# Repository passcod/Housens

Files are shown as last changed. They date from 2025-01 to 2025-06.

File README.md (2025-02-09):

# Housens

Project to make my own low-power house sensors.

Current iteration (r002):

- Bluetooth
- ambient light (OPT3005)
- pressure, humidity, temperature (BME280)
- carbon dioxide (STCC4)
- STM32WB core
- powered from CR2032
- 50x50mm

Hardware licensed [CERN-OHL-S](https://ohwr.org/project/cernohl/-/wikis/uploads/b236492596cfc91c12def7d50bbf7da0/cern_ohl_s_v2.pdf).

Firmware licensed [GPL-3.0-or-later](https://opensource.org/license/gpl-3-0).

## Renders

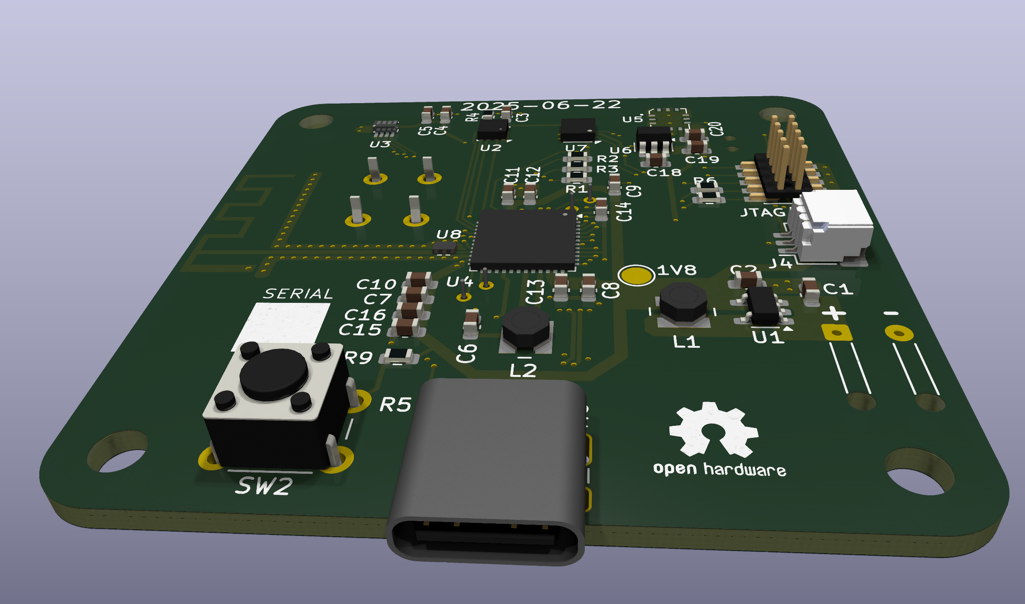
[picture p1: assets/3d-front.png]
front 3D render


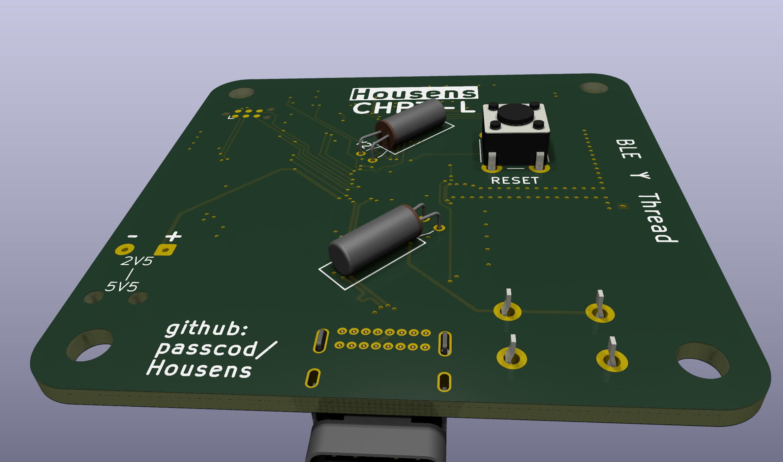
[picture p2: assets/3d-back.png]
back 3D render


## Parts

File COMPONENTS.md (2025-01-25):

# Components

- BME280 sensor
  - Temperature, Humidity, Pressure
  - 3.6 uA @ 1Hz typical
  - 1.8V power
- OPT3005 sensor
  - Ambient light, with IR filter
  - 1.8 uA typical
  - 1.8V power
- STM32WB
  - STM32WB55CG   (LCD,   1MB flash / 256kB ram), or:
    - STM32WB55CE (LCD, 512kB flash / 256kB ram)
    - STM32WB55CC (LCD, 256kB flash / 128kB ram)
    - STM32WB35CE (---, 512kB flash /  96kB ram)
    - STM32WB35CC (---, 256kB flash /  96kB ram)
  - ARM Cortex-M4
  - BLE5 and Thread
  - 1.8V power
  - 90 uA per MHz, up to 64MHz
  - Rust support
- CR2032
  - 2.7V flat
  - 3V nominal
  - 3.4V max
  - 210 mAh typical
- MCP1603
  - Voltage switching regulator
  - 2.7 - 4.5V input
  - 1.8V output
  - 45 uA quiescent, 0.1 uA shutdown
  - 500 mA max output

## Power usage

- load: 3.6 uA + 1.8 uA + 90 uA * 64 + 45 uA = ~6mA
- so ~36 hour battery life @ 1Hz update constant power

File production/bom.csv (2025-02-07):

Designator | Footprint | Quantity | Value | LCSC Part #
AE1 | Texas_SWRA117D_2.4GHz_Right_BigHole | 1 | 2.4GHz
BT1 | BAT-HLD-001_2Pins | 1 | CR2032
C1, C10, C13, C2, C6 | 0603 | 5 | 4.7u
C11 | 0603 | 1 | 10n
C12 | 0603 | 1 | 1u
C14, C15, C3, C4, C5, C7, C8, C9 | 0603 | 8 | 100n
C16 | 0603 | 1 | 100p
C18, C19, C20 | 0603 | 3 | 220n
J1 | PinHeader_2x05_P1.27mm_Vertical_SMD | 1 | JTAG/SWD
J2 | USB_C_Receptacle_GCT_USB4085 | 1 | USB_C_2.0
J4 | JST_SH_SM03B-SRSS-TB_1x03-1MP_P1.00mm_Horizontal | 1 | RPI_SWD
L1 | L_Wuerth_WE-TPC-2811 | 1 | 4.7u
L2 | L_Wuerth_WE-TPC-2811 | 1 | 2.2u
R1, R2, R3, R5, R9 | 0603 | 5 | 10k
R4 | 0603 | 1 | 100k
R6, R7 | 0603 | 2 | 100
SW1 | SW_PUSH_6mm | 1 | RESET
SW2 | SW_PUSH_6mm | 1 | USER
TP1 | TestPoint_Pad_D2.0mm | 1 | TestPoint
U1 | TSOT-23-5 | 1 | LM3670MF
U2 | Bosch_LGA-8_2.5x2.5mm_P0.65mm_ClockwisePinNumbering | 1 | BME280
U3 | OPT3005DTSR | 1 | OPT3005
U4 | QFN-48-1EP_7x7mm_P0.5mm_EP5.6x5.6mm_ThermalVias_OneSided | 1 | STM32WB55CGUx
U5 | STCC4-PROVISIONAL | 1 | STCC4
U6 | SOT-23-6 | 1 | REG710NA-3.3
U7 | DFN-14-1EP_3x2mm_P0.4mm_EP1.78x1.35mm_AP22966 | 1 | AP22966
U8 | MLPF-WB55-01E3 | 1 | MLPF-WB55-01E3
Y1 | Crystal_SMD_2016-4Pin_2.0x1.6mm | 1 | 32MHz
Y2 | Crystal_AT310_D3.0mm_L10.0mm_Horizontal | 1 | 32.768kHz

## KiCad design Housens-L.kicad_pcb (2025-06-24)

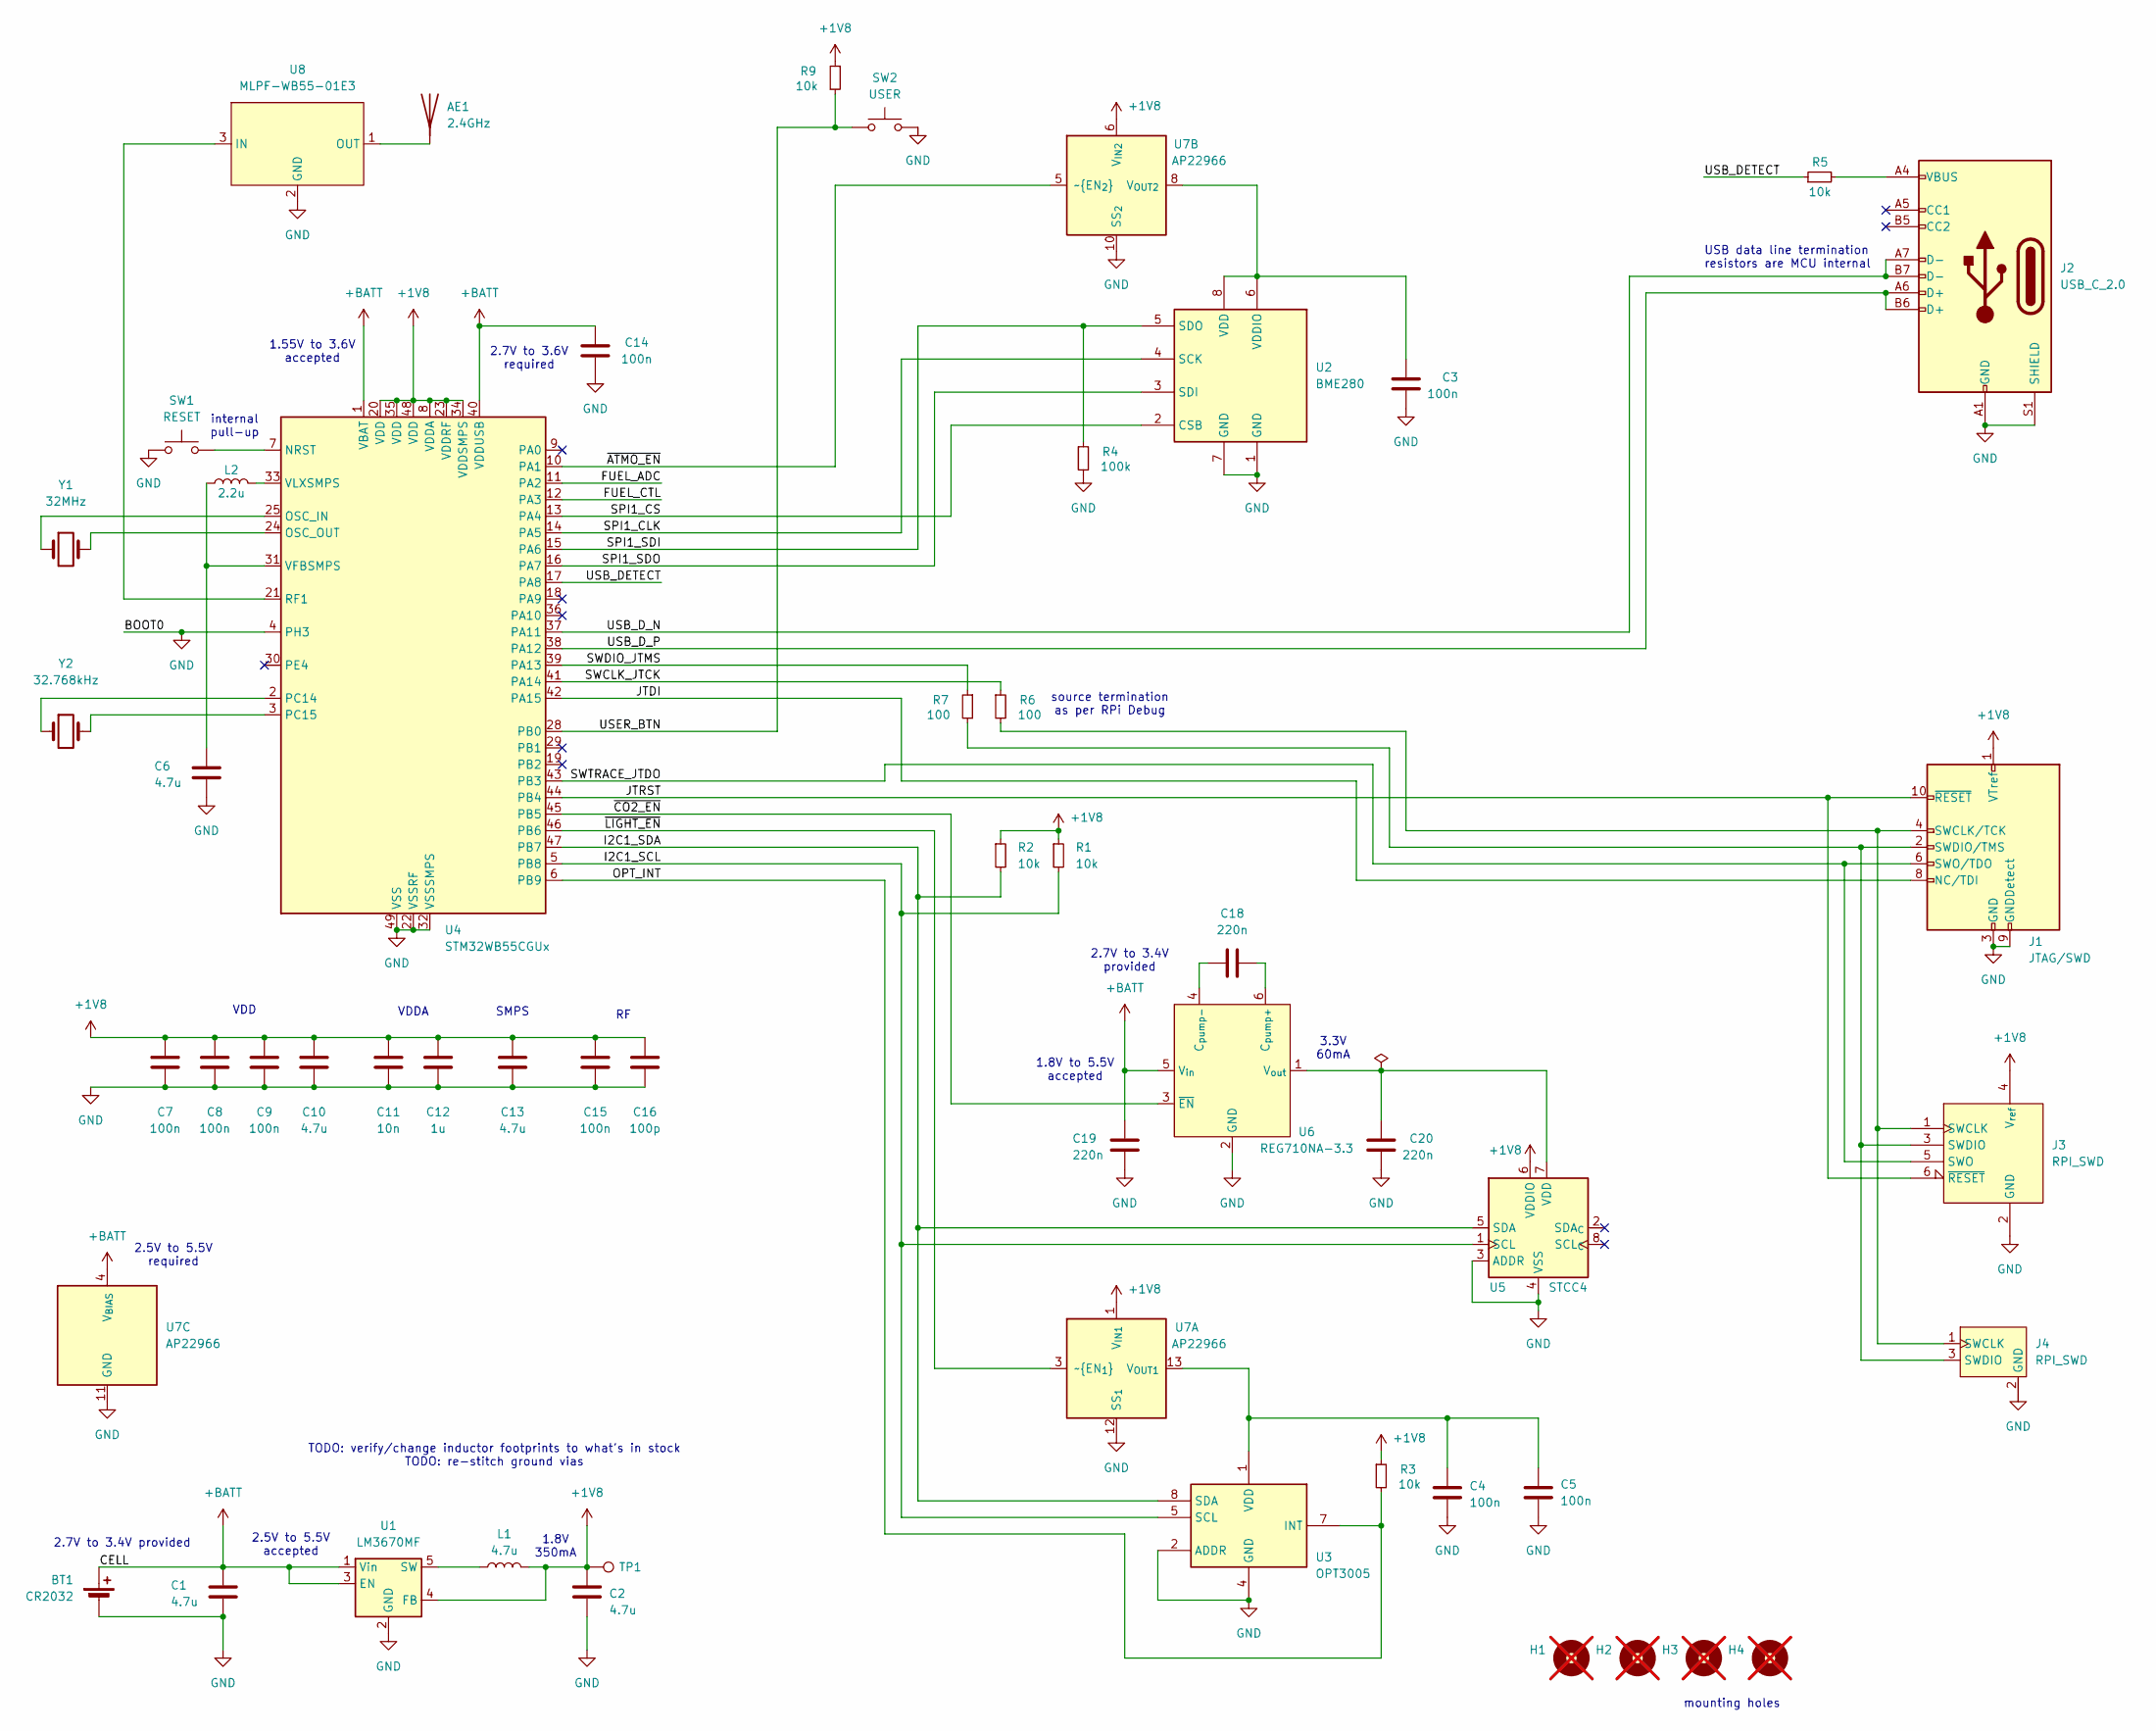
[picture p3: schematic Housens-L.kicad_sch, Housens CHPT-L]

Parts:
AE1: 2.4GHz; Texas_SWRA117D_2.4GHz_Right_BigHole
BT1: CR2032; SolderWire-0.1sqmm_1x02_P3.6mm_D0.4mm_OD1mm_Relief
C1, C2, C6, C10, C13: 4.7u; C_0603_1608Metric
C3, C4, C5, C7, C8, C9, C14, C15: 100n; C_0603_1608Metric
C11: 10n; C_0603_1608Metric
C12: 1u; C_0603_1608Metric
C16: 100p; C_0603_1608Metric
C18, C19, C20: 220n; C_0603_1608Metric
H1, H2, H3, H4: MountingHole_M3; MountingHole_3.2mm_M3; not fitted
J1: JTAG/SWD; PinHeader_2x05_P1.27mm_Vertical_SMD
J2: USB_C_2.0; USB_C_Receptacle_GCT_USB4085
J3: RPI_SWD; Tag-Connect_TC2030-IDC-NL_2x03_P1.27mm_Vertical
J4: RPI_SWD; JST_SH_SM03B-SRSS-TB_1x03-1MP_P1.00mm_Horizontal
L1: 4.7u; L_Wuerth_WE-TPC-2811
L2: 2.2u; L_Wuerth_WE-TPC-2811
R1, R2, R3, R5, R9: 10k; R_0603_1608Metric
R4: 100k; R_0603_1608Metric
R6, R7: 100; R_0603_1608Metric
SW1: RESET; SW_PUSH_6mm
SW2: USER; SW_PUSH_6mm
TP1: TestPoint; TestPoint_Pad_D2.0mm
U1: LM3670MF; TSOT-23-5; Part LM3670MFX-1.8/NOPB
U2: BME280; Bosch_LGA-8_2.5x2.5mm_P0.65mm_ClockwisePinNumbering
U3: OPT3005; OPT3005DTSR; Manufacturer_Part_Number OPT3005DTSR; Mouser Part Number 595-OPT3005DTSR
U4: STM32WB55CGUx; QFN-48-1EP_7x7mm_P0.5mm_EP3.5x3.5mm
U5: STCC4
U6: REG710NA-3.3; SOT-23-6
U7: AP22966; DFN-14-1EP_3x2mm_P0.4mm_EP1.78x1.35mm_AP22966
U8: MLPF-WB55-01E3
Y1: 32MHz; Crystal_C38-LF_D3.0mm_L8.0mm_Horizontal
Y2: 32.768kHz; Crystal_C38-LF_D3.0mm_L8.0mm_Horizontal

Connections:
+1V8: C2.1, C7.1, C8.1, C9.1, C10.1, C11.1, C12.1, C13.1, C15.1, C16.1, J1.1 (VTref), J3.4 (V_{ref}), L1.2, R1.1, R2.1, R3.1, R9.1, TP1.1, U1.4 (FB), U4.8 (VDDA), U4.20 (VDD), U4.23 (VDDRF), U4.34 (VDDSMPS), U4.35 (VDD), U4.48 (VDD), U5.6 (VDDIO), U7.1 (V_{IN1}), U7.2 (V_{IN1}), U7.6 (V_{IN2}), U7.7 (V_{IN2})
+BATT: BT1.1 (+), C1.1, C14.1, C19.1, U1.1 (Vin), U1.3 (EN), U4.1 (VBAT), U4.40 (VDDUSB), U6.5 (V_{in}), U7.4 (V_{BIAS})
/FUEL_ADC: U4.11 (PA2)
/FUEL_CTL: U4.12 (PA3)
/I2C1_SCL: R1.2, U3.5 (SCL), U4.5 (PB8), U5.1 (SCL)
/I2C1_SDA: R2.2, U3.8 (SDA), U4.47 (PB7), U5.5 (SDA)
/JTDI: J1.8 (NC/TDI), U4.42 (PA15)
/JTRST: J1.10 (~RESET), J3.6 (~RESET), U4.44 (PB4)
/OPT_INT: R3.2, U3.7 (INT), U4.6 (PB9)
/SPI1_CLK: U2.4 (SCK), U4.14 (PA5)
/SPI1_CS: U2.2 (CSB), U4.13 (PA4)
/SPI1_SDI: R4.1, U2.5 (SDO), U4.15 (PA6)
/SPI1_SDO: U2.3 (SDI), U4.16 (PA7)
/SWCLK_JTCK: R6.1, U4.41 (PA14)
/SWDIO_JTMS: R7.1, U4.39 (PA13)
/SWTRACE_JTDO: J1.6 (SWO/TDO), J3.5 (SWO), U4.43 (PB3)
/USB_DETECT: R5.1, U4.17 (PA8)
/USB_D_N: J2.A7 (D-), J2.B7 (D-), U4.37 (PA11)
/USB_D_P: J2.A6 (D+), J2.B6 (D+), U4.38 (PA12)
/USER_BTN: R9.2, SW2.2, U4.28 (PB0)
/~ATMO_EN: U4.10 (PA1), U7.5 (~EN_{2})
/~CO2_EN: U4.45 (PB5), U6.3 (~EN)
/~LIGHT_EN: U4.46 (PB6), U7.3 (~EN_{1})
GND: BT1.2 (-), C1.2, C2.2, C3.2, C4.2, C5.2, C6.2, C7.2, C8.2, C9.2, C10.2, C11.2, C12.2, C13.2, C14.2, C15.2, C16.2, C19.2, C20.2, J1.3 (GND), J1.5 (GND), J1.9 (GNDDetect), J2.A1 (GND), J2.A12 (GND), J2.B1 (GND), J2.B12 (GND), J2.S1 (SHIELD), J3.2 (GND), J4.2 (GND), R4.2, SW1.1, SW2.1, U1.2 (GND), U2.1 (GND), U2.7 (GND), U3.2 (ADDR), U3.4 (GND), U4.4 (PH3), U4.22 (VSSRF), U4.32 (VSSSMPS), U4.49 (VSS), U5.3 (ADDR), U5.4 (VSS), U6.2 (GND), U7.10 (SS_{2}), U7.11 (GND), U7.12 (SS_{1}), U7.15 (GND), U8.2 (GND), U8.4 (GND), U8.5 (GND), U8.6 (GND)
unnamed: AE1.1 (A), U8.1 (OUT)
unnamed: J1.4 (SWCLK/TCK), J3.1 (SWCLK), J4.1 (SWCLK), R6.2
unnamed: J1.2 (SWDIO/TMS), J3.3 (SWDIO), J4.3 (SWDIO), R7.2
unnamed: J2.A4 (VBUS), J2.A9 (VBUS), J2.B4 (VBUS), J2.B9 (VBUS), R5.2
unnamed: L1.1, U1.5 (SW)
unnamed: C3.1, U2.6 (VDDIO), U2.8 (VDD), U7.8 (V_{OUT2}), U7.9 (V_{OUT2})
unnamed: C4.1, C5.1, U3.1 (VDD), U7.13 (V_{OUT1}), U7.14 (V_{OUT1})
unnamed: SW1.2, U4.7 (NRST)
unnamed: U4.25 (OSC_IN), Y1.1
unnamed: U4.24 (OSC_OUT), Y1.2
unnamed: U4.2 (PC14), Y2.1
unnamed: U4.3 (PC15), Y2.2
unnamed: U4.21 (RF1), U8.3 (IN)
unnamed: C6.1, L2.1, U4.31 (VFBSMPS)
unnamed: L2.2, U4.33 (VLXSMPS)
unnamed: C20.1, U5.7 (VDD), U6.1 (V_{out})
unnamed: C18.2, U6.6 (C_{pump+})
unnamed: C18.1, U6.4 (C_{pump-})

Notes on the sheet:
SMPS
1.8V to 5.5V accepted
2.7V to 3.6V required
2.5V to 5.5V accepted
3.3V 60mA
2.7V to 3.4V provided
internal pull-up
2.7V to 3.4V provided
TODO: verify/change inductor footprints to what's in stock TODO: re-stitch ground vias
1.8V 350mA
source termination as per RPi Debug
mounting holes
USB data line termination resistors are MCU internal
2.5V to 5.5V required
VDDA
VDD
1.55V to 3.6V accepted

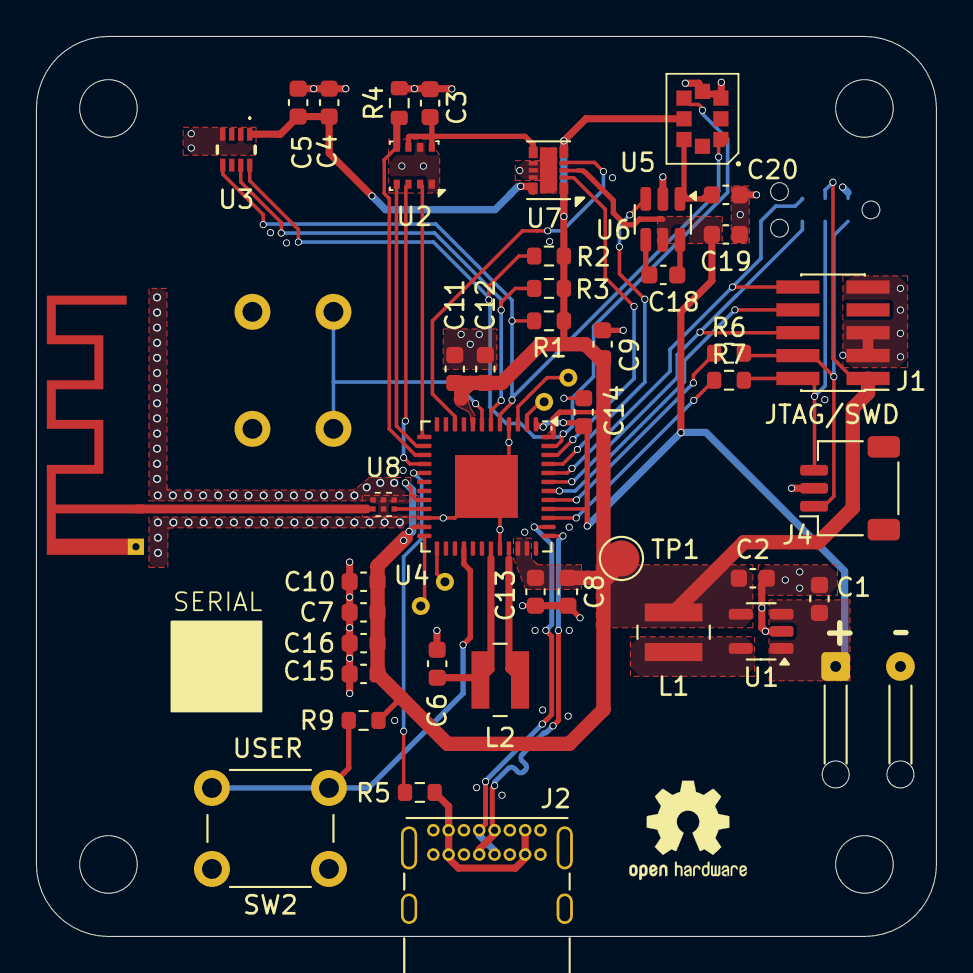
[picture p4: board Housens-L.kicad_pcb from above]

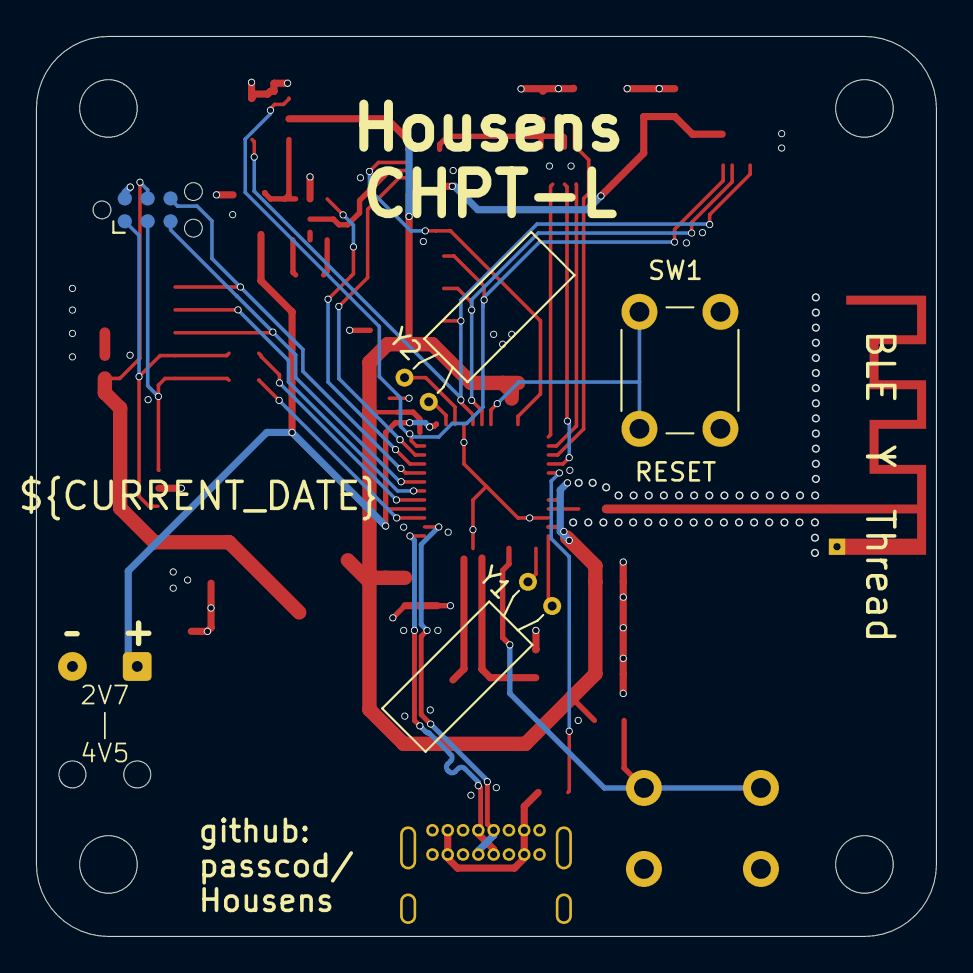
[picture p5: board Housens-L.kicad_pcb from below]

Board: 4 copper layers, 50.0 x 50.0 mm, 52 parts (4 on the bottom side), 40 nets.

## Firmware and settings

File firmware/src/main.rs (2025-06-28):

#![no_std]
#![no_main]

use defmt::*;
use embassy_executor::Spawner;
use embassy_stm32::gpio::{Level, Output, Speed, Input, Pull};
use embassy_time::Timer;
use {defmt_rtt as _, panic_probe as _};

#[embassy_executor::main]
async fn main(_spawner: Spawner) {
    let p = embassy_stm32::init(Default::default());
    info!("Hello World!");

    let mut led = Output::new(p.PB0, Level::High, Speed::Low);
    let mq = Input::new(p.PB2, Pull::Up);
    led.set_high();

    loop {
        if mq.is_low() {
            info!("pin low");
            led.set_low();
        } else {
            info!("pin high");
            led.set_high();
        }

        //led.set_high();
        Timer::after_millis(200).await;
        //led.set_low();
        Timer::after_millis(200).await;
    }
}

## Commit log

2025-01-25 Add power supply
    [Housens-L.kicad_sch]
2025-01-25 Add sensors
    [Housens-L.kicad_sch]
2025-01-25 Add MCU
    [Housens-L.kicad_sch]
2025-01-25 Add battery
    [Housens-L.kicad_sch]
2025-01-25 Add debug connector
    [Housens-L.kicad_sch]
2025-01-25 Add USB connector
    [Housens-L.kicad_sch]
2025-01-25 Layout board edge
    [Housens-L.kicad_pcb]
2025-01-25 Initial spatial layout
    [Housens-L.kicad_pcb, Housens-L.kicad_sch]
2025-01-25 Layout power supply
    [Housens-L.kicad_pcb]
2025-01-25 Add TODO about touchsense
    [Housens-L.kicad_pcb, Housens-L.kicad_sch]
2025-01-26 Layout antenna
    [Housens-L.kicad_pcb, Housens-L.kicad_sch]
2025-01-26 Add fuel gauge
    [Housens-L.kicad_pcb, Housens-L.kicad_sch]
2025-01-26 Custom thermal footprint for MCU
    [Housens-L.kicad_pcb, Housens-L.kicad_sch]
2025-01-26 Layout 1V8 and USB
    [Housens-L.kicad_pcb, Housens-L.kicad_sch]
2025-01-26 Layout JTAG
    [Housens-L.kicad_pcb]
2025-01-26 Add 3D model for cell holder
    [Housens-L.kicad_pcb, Housens-L.kicad_sch]
2025-01-26 Show some labels
    [Housens-L.kicad_pcb, Housens-L.kicad_sch]
2025-01-26 Layout BME280
    [Housens-L.kicad_pcb]
2025-01-26 Layout I2C
    [Housens-L.kicad_pcb, Housens-L.kicad_sch]
2025-01-26 Layout SPI
    [Housens-L.kicad_pcb]
2025-01-26 Impedance-match USB lines
    [Housens-L.kicad_pcb, Housens-L.kicad_sch]
2025-01-26 Stitch and finalise labels
    [Housens-L.kicad_pcb]
2025-01-26 Generate production files
    [bom.csv, designators.csv, positions.csv]
2025-01-26 Replace crystals
    [Housens-L.kicad_pcb, Housens-L.kicad_sch]
2025-01-26 Run DRC
    [Housens-L.kicad_pcb, bom.csv, positions.csv]
2025-01-26 Replace vias with the cheap ones
    [Housens-L.kicad_pcb]
2025-01-26 Add datasheet for buttons
    [Housens-L.kicad_pcb]
2025-01-27 Fix hole sizes
    [Housens-L.kicad_pcb, Housens-L.kicad_sch, bom.csv]
2025-01-27 More hole size fixes
    [Housens-L.kicad_pcb]
2025-01-27 Add license
    [Housens-L.kicad_sch]
2025-01-28 Fix 3D view
    [Housens-L.kicad_pcb]
2025-01-29 Remove external fuel measurement as MCU has one built in
    [Housens-L.kicad_sch]
2025-01-29 Add power control to peripherals
    [Housens-L.kicad_sch]
2025-01-29 Add provisional STCC4 sensor
    [Housens-L.kicad_sch]
2025-01-29 Add note on upcoming sensor
    [Housens-L.kicad_sch]
2025-01-30 Add power supply for SCCT4 and dual fets for others
    [Housens-L.kicad_sch]
2025-01-30 Layout for recent changes
    [Housens-L.kicad_pcb, Housens-L.kicad_sch]
2025-01-30 Relayout debug port
    [Housens-L.kicad_pcb]
2025-01-30 According to TI, the antenna via should go to ground
    [Housens-L.kicad_pcb]
2025-02-03 Use proper load switch instead of plain FET
    [Housens-L-B_Cu.gbr, Housens-L-B_Mask.gbr, Housens-L-B_Paste.gbr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]
2025-02-03 Add matching circuit to antenna
    [Housens-L-B_Cu.gbr, Housens-L-B_Mask.gbr, Housens-L-B_Paste.gbr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]
2025-02-03 Space out the sensors
    [Housens-L-B_Cu.gbr, Housens-L-B_Mask.gbr, Housens-L-B_Paste.gbr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]
2025-02-03 Replace matching circuit with IPD
    This is more compact, purpose-made, and cheaper than the individual components!
    [Housens-L-B_Cu.gbr, Housens-L-B_Mask.gbr, Housens-L-B_Paste.gbr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]
2025-02-06 Use LM voltage reg instead of unobtainium MCP
    [Housens-L-B_Cu.gbr, Housens-L-B_Mask.gbr, Housens-L-B_Paste.gbr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]
2025-02-07 Add RPi-style debug port
    [Housens-L.kicad_pcb, Housens-L.kicad_sch]
2025-02-07 Make STCC4 silk prettier
    [Housens-L.kicad_pcb]
2025-02-07 Update production files
    [Housens-L-B_Cu.gbr, Housens-L-B_Mask.gbr, Housens-L-B_Paste.gbr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]
2025-02-08 Restitch at 1/20th wavelength
    [Housens-L.kicad_pcb]
2025-05-06 updates from sourcing hardware
    [Housens-L.kicad_pcb, Housens-L.kicad_sch]
2025-06-22 Replace soldered CR battery holder with wire connections
    - it liberates a large amount of board space
    - soldering this thing was really annoying to do by hand
    - a significant problem turns out to be that in high-condensation environment
    (e.g. outside) the battery drains itself via conduction through the humidity
    on the cell, reducing battery life from months to days. being able to seal
    the battery separately from the sensors / rest of the board is an advantage.
    [Housens-L.kicad_pcb, Housens-L.kicad_sch]
2025-06-24 Use released STCC4 details
    [Housens-L.kicad_pcb, Housens-L.kicad_sch]
